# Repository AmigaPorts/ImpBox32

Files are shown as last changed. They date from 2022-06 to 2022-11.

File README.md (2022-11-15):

# ImpBox32

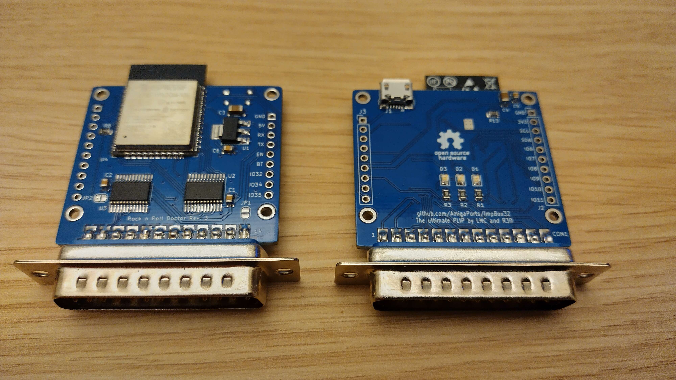
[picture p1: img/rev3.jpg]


This device provides wireless connectivity to your Amiga.
The primary purpose is for use with [IMP](http://aminet.net/package/mus/play/imp3), but with proper firmware it can act as general-purpose network interface.

## Using the IMP firmware

### Flashing the device

Flash the device with firmware from `firmware_impbox` directory - you can use RX/TX pin header for this using typical ESP32 tooling.
Assuming that your COM port is /dev/ttyUSB0:

```plain
esptool --chip esp32 --port /dev/ttyUSB0 --baud 921600 --before default_reset --after hard_reset write_flash -z --flash_mode dio --flash_freq 80m --flash_size 4MB \
0x1000 bootloader.bin \
0x8000 partitions.bin \
0xe000 boot_app0.bin \
0x10000 fw_36.bin
```

The IMP firmware automatically updates itself, so you need to flash it manually only once.

### Using with IMP3

The firmware makes use of SD1306 or compatible OLED I2C display - be sure to connect one at least during registration and configuration phase.

The IMP firmware requires inputing registration key.
Getting the key is free but they are issued per-person to limit users during beta phase.
Contact Juen on EAB for getting one.
See messages displayed on OLED for detailed instructions on how to enter your key.

to configure WiFi network, use following commands:

```plain
imp3 ibcs your_ssid
imp3 ibcp your_password
imp3 ibcc your_key
```

Device stores the key as well as network parameters in its flash memory, hence configuration needs to be done only once.
Once configured, to launch IMP, type:

```plain
imp3 ib
```

## Differences between PCB revisions

Be sure to use the latest PCB revision - old ones are buggy and not supported.

The board currently recommended by IMP authors is rev3.
There's also rev3s board with SD card slot which cauld be made to work with modified sdbox firmware, and will be eventually suported by the universal firmware.

## Using the universal firmware

TBD - this firmware is currently not available.

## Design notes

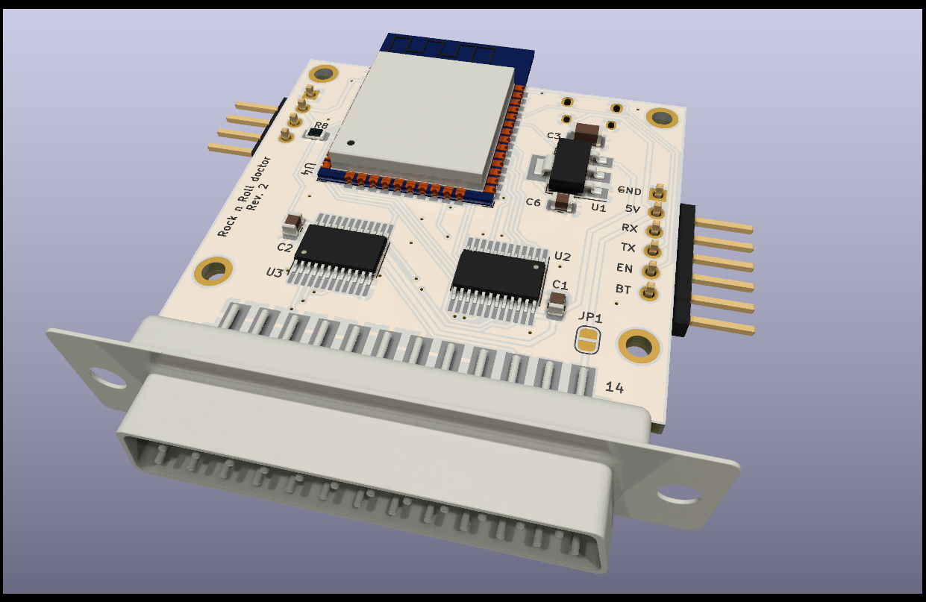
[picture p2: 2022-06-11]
img/back.png

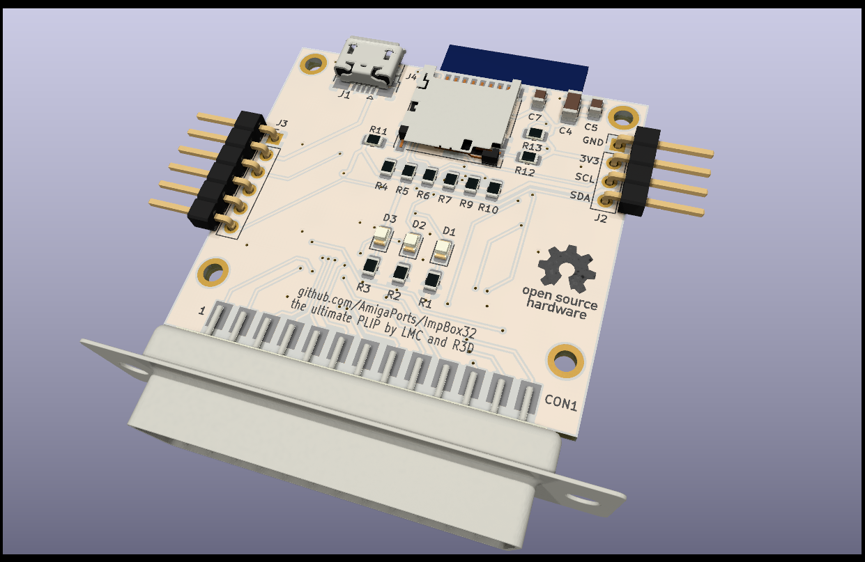
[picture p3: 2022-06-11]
img/front.png

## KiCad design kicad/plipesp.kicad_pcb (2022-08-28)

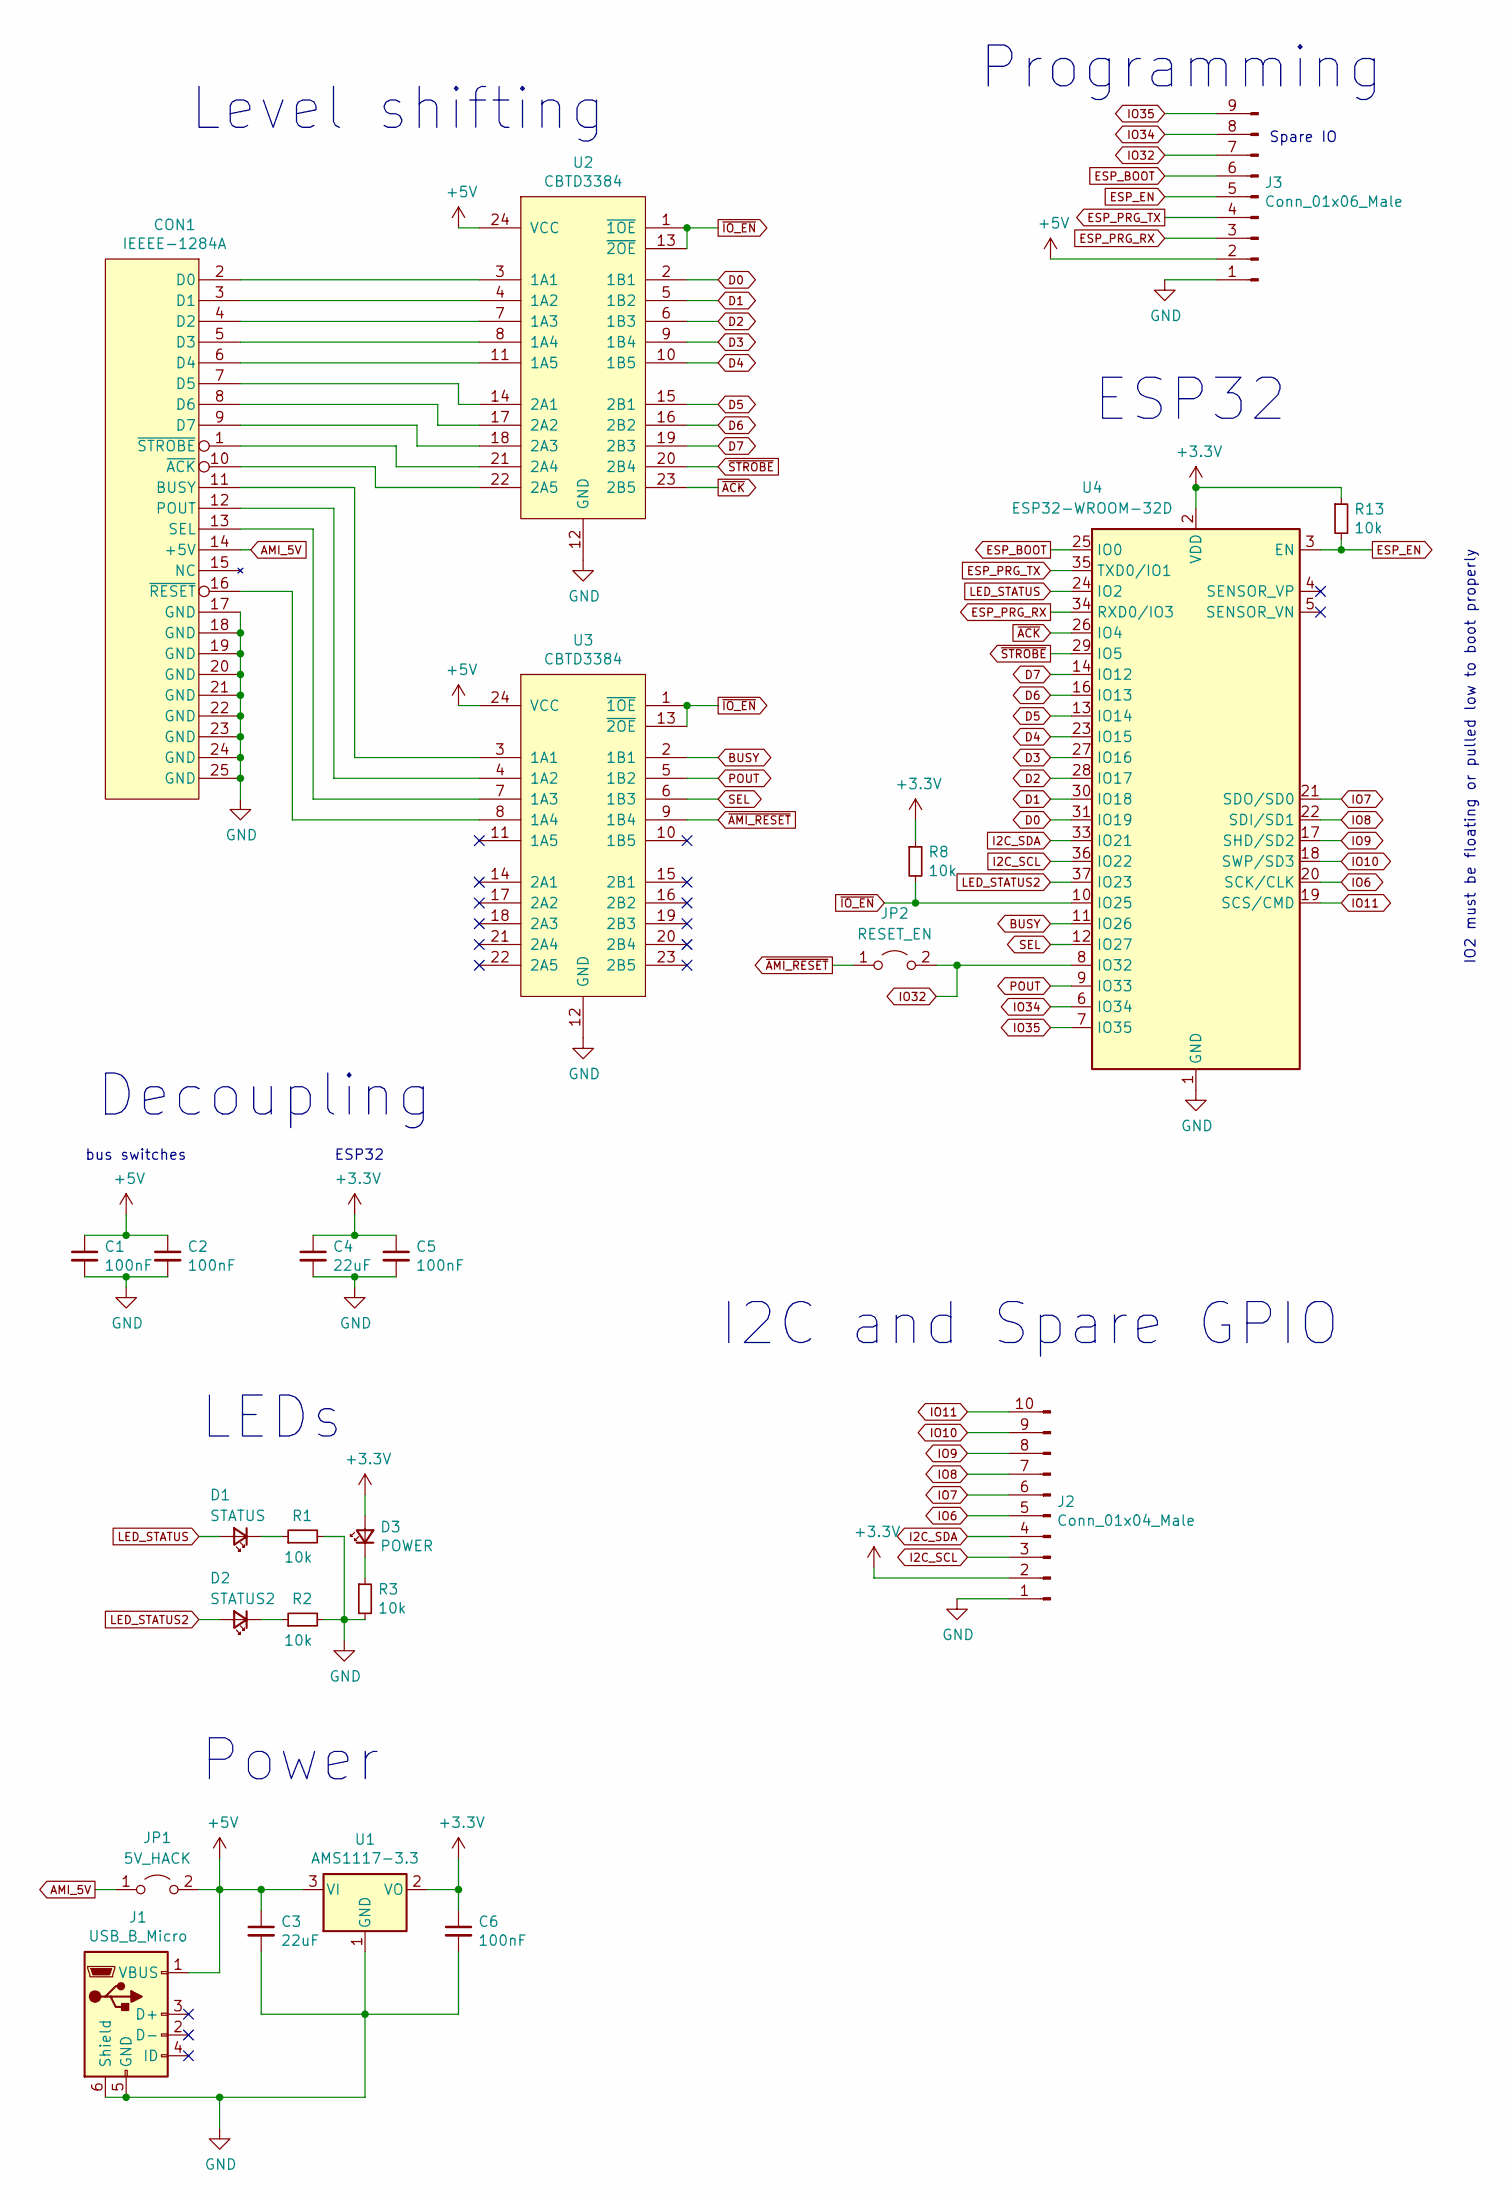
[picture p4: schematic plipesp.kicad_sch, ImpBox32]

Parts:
C1, C2, C5, C6: 100nF; C_0805_2012Metric
C3, C4: 22uF; C_1206_3216Metric
CON1: IEEEE-1284A; d-sub25_edge
D1: STATUS; LED_0805_2012Metric
D2: STATUS2; LED_0805_2012Metric
D3: POWER; LED_0805_2012Metric
J1: USB_B_Micro; USB_Micro-B_Amphenol_10103594-0001LF_Horizontal
J2: Conn_01x04_Male; PinHeader_1x10_P2.54mm_Vertical
J3: Conn_01x06_Male; PinHeader_1x09_P2.54mm_Vertical
JP1: 5V_HACK; SolderJumper-2_P1.3mm_Open_RoundedPad1.0x1.5mm
JP2: RESET_EN; SolderJumper-2_P1.3mm_Open_RoundedPad1.0x1.5mm
R1, R2, R3, R8, R13: 10k; R_0805_2012Metric
U1: AMS1117-3.3; SOT-223-3_TabPin2
U2, U3: CBTD3384; SO-universal-24_P0.65mm
U4: ESP32-WROOM-32D; ESP32-WROOM-32

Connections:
+3V3: C4.1, C5.1, C6.1, D3.2 (A), J2.2, R8.1, R13.1, U1.2 (VO), U4.2 (VDD)
+5V: C1.1, C2.1, C3.1, J1.1 (VBUS), J3.2, JP1.2 (B), U1.3 (VI), U2.24 (VCC), U3.24 (VCC)
AMI_5V: CON1.14 (+5V), JP1.1 (A)
BUSY: U3.2 (1B1), U4.11 (IO26)
D0: U2.2 (1B1), U4.31 (IO19)
D1: U2.5 (1B2), U4.30 (IO18)
D2: U2.6 (1B3), U4.28 (IO17)
D3: U2.9 (1B4), U4.27 (IO16)
D4: U2.10 (1B5), U4.23 (IO15)
D5: U2.15 (2B1), U4.13 (IO14)
D6: U2.16 (2B2), U4.16 (IO13)
D7: U2.19 (2B3), U4.14 (IO12)
ESP_BOOT: J3.6, U4.25 (IO0)
ESP_EN: J3.5, R13.2, U4.3 (EN)
ESP_PRG_RX: J3.3, U4.34 (RXD0/IO3)
ESP_PRG_TX: J3.4, U4.35 (TXD0/IO1)
GND: C1.2, C2.2, C3.2, C4.2, C5.2, C6.2, CON1.17 (GND), CON1.18 (GND), CON1.19 (GND), CON1.20 (GND), CON1.21 (GND), CON1.22 (GND), CON1.23 (GND), CON1.24 (GND), CON1.25 (GND), J1.5 (GND), J1.6 (Shield), J2.1, J3.1, R1.2, R2.2, R3.2, U1.1 (GND), U2.12 (GND), U3.12 (GND), U4.1 (GND), U4.15 (GND), U4.38 (GND), U4.39 (GND)
I2C_SCL: J2.3, U4.36 (IO22)
I2C_SDA: J2.4, U4.33 (IO21)
IO6: J2.5, U4.20 (SCK/CLK)
IO7: J2.6, U4.21 (SDO/SD0)
IO8: J2.7, U4.22 (SDI/SD1)
IO9: J2.8, U4.17 (SHD/SD2)
IO10: J2.9, U4.18 (SWP/SD3)
IO11: J2.10, U4.19 (SCS/CMD)
IO32: J3.7, JP2.2 (B), U4.8 (IO32)
IO34: J3.8, U4.6 (IO34)
IO35: J3.9, U4.7 (IO35)
LED_STATUS: D1.2 (A), U4.24 (IO2)
LED_STATUS2: D2.2 (A), U4.37 (IO23)
unnamed: CON1.1 (~STROBE), U2.21 (2A4)
unnamed: CON1.2 (D0), U2.3 (1A1)
unnamed: CON1.3 (D1), U2.4 (1A2)
unnamed: CON1.4 (D2), U2.7 (1A3)
unnamed: CON1.5 (D3), U2.8 (1A4)
unnamed: CON1.6 (D4), U2.11 (1A5)
unnamed: CON1.7 (D5), U2.14 (2A1)
unnamed: CON1.8 (D6), U2.17 (2A2)
unnamed: CON1.9 (D7), U2.18 (2A3)
unnamed: CON1.10 (~ACK), U2.22 (2A5)
unnamed: CON1.11 (BUSY), U3.3 (1A1)
unnamed: CON1.12 (POUT), U3.4 (1A2)
unnamed: CON1.13 (SEL), U3.7 (1A3)
unnamed: CON1.16 (~RESET), U3.8 (1A4)
unnamed: D1.1 (K), R1.1
unnamed: D2.1 (K), R2.1
unnamed: D3.1 (K), R3.1
POUT: U3.5 (1B2), U4.9 (IO33)
SEL: U3.6 (1B3), U4.12 (IO27)
~ACK: U2.23 (2B5), U4.26 (IO4)
~AMI_RESET: JP2.1 (A), U3.9 (1B4)
~IO_EN: R8.2, U2.1 (~1OE), U2.13 (~2OE), U3.1 (~1OE), U3.13 (~2OE), U4.10 (IO25)
~STROBE: U2.20 (2B4), U4.29 (IO5)

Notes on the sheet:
bus switches
IO2 must be floating or pulled low to boot properly
I2C and Spare GPIO
ESP32
Programming
LEDs
Spare IO
Power
Decoupling
Level shifting

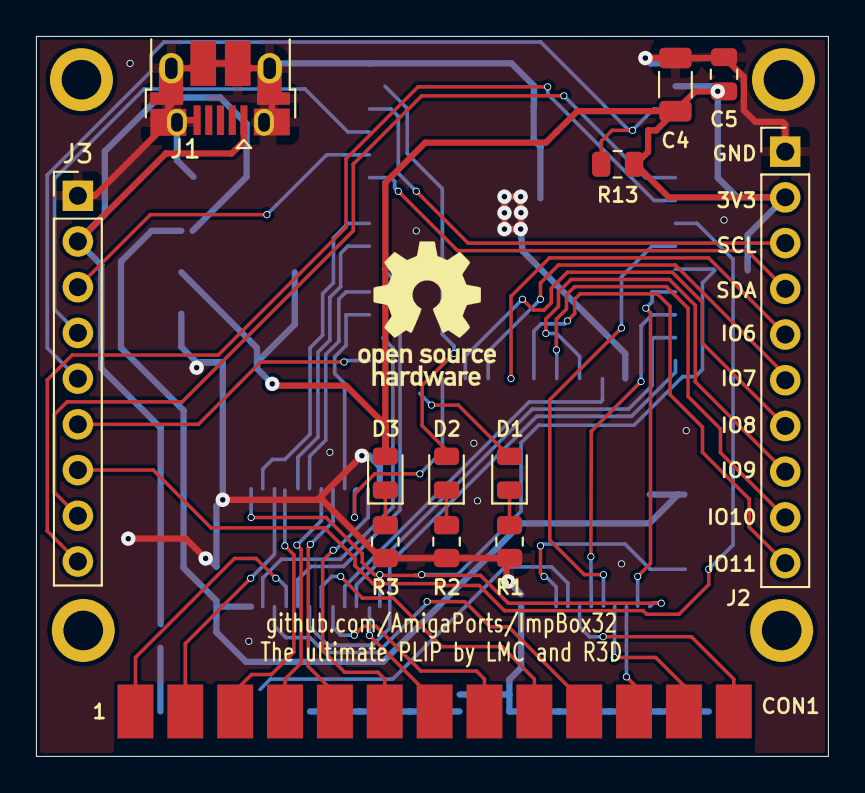
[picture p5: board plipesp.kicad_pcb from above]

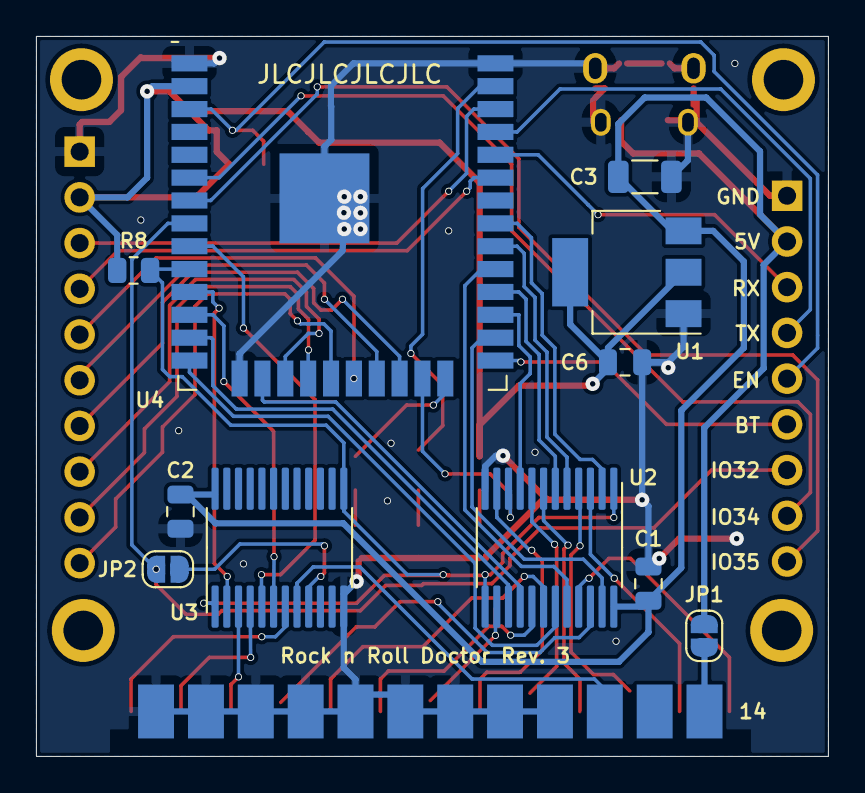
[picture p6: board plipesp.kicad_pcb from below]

Board: 2 copper layers, 44.0 x 40.0 mm, 28 parts (11 on the bottom side), 53 nets.

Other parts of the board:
REF1, REF2, REF3, REF4: mounting_hole

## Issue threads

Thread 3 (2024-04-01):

Plipbox.device

levo-man, 2024-04-01:
More a question , is plipbox.device compatible with this , if not then is there a driver coming out for it ?

tehKaiN, 2024-04-01:
Not yet. Requires universal firmware, which is yet to be made.

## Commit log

2022-06-09 board rev1
    [plipesp.kicad_pcb, plipesp.sch]
2022-06-11 board rev2
    [plipesp.kicad_pcb, plipesp.kicad_sch]
2022-08-28 rev3s - with SD card
    [plipesp.kicad_pcb, plipesp.kicad_sch]
2022-08-28 rev3 - without SD card, AMI_RESET optional, extra IO on pins
    [plipesp.kicad_pcb, plipesp.kicad_sch]
2022-10-30 upload full fw
    Full firmware package to upload into fresh ESP32
2022-11-13 Update README.md
    fixed fw name, and correct arduino bootloader, partitions, boot_app files
